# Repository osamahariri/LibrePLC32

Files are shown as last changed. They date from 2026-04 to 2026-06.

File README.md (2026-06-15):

<p align="center">
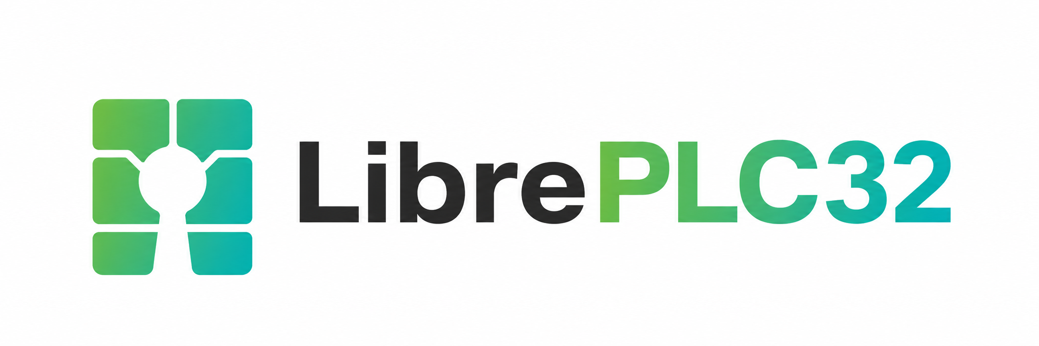
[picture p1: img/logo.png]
LibrePLC32 logo
  
</p>

# LibrePLC32

**LibrePLC32** is an open-source, KiCad-based Programmable Logic Controller (PLC) hardware project.

The goal of the project is to create a compact, hackable, and well-documented PLC platform for industrial automation experiments, prototyping, education, and open hardware development.

> ⚠️ **Work in progress:** LibrePLC32 is currently under development.

<p align="center">
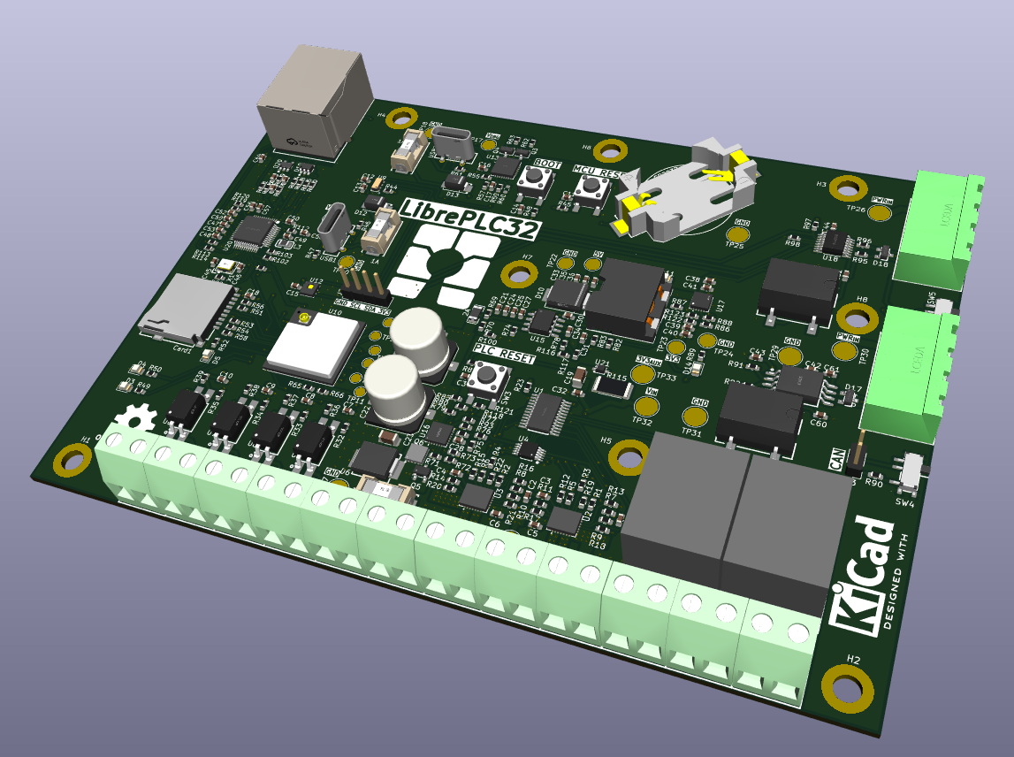
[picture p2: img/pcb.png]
  
</p>

## Project goals

LibrePLC32 aims to provide:

- An open hardware PLC design
- KiCad source files for schematic and PCB development
- Field-oriented interfaces such as digital I/O, isolated CAN, isolated RS-485, and Ethernet
- A design that can be studied, modified, repaired, and improved by the community
- Documentation for design decisions and component calculations

## Repository structure

```text
.
├── img/              # Project logo and graphics
├── plc/
│   ├── docs/         # Design notes and calculations
│   └── kicad/        # KiCad project, schematics, PCB, and libraries
├── LICENSE
└── README.md
```

## Features

LibrePLC32 is designed to provide a practical set of PLC-oriented hardware features:

- **8–36 V DC input voltage range**
- **4 isolated digital inputs** for field signals
- **4 transistor digital outputs** for driving external loads
- **2 relay output terminals** for switching isolated loads
- **Isolated RS-485 interface** for industrial serial communication
- **Isolated CAN bus interface** for device-to-device communication
- **Ethernet interface** for network connectivity

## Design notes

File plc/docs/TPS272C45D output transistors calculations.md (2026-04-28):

# TPS272C45D Output Transistors

Used for outputting power to channels 1-4.

Variant 'D' has dual fault FLT1/FLT2 to provide detailed fault diagnosis.
[Product Link](https://www.ti.com/product/TPS272C45/part-details/TPS272C45DRHFR)

## Current limit

The current limit for each channel is measured using the following formula:
`I_CL = K_CL / R_ILIM`,

with the constant `K_CL` being 20.5 A.kΩ. `R_ILIM` is limited between 5 kΩ and 28.2 kΩ.
Using 5.1 kΩ resistors this will put the output current at a maximum of 4.02 A.

## Current sense
The `SNS` pin outputs a current that is proportional to the load current through either channel, depending on the state of the `SEL` pin.
When the `SEL` is low, `SNS` outputs load current proportional to channel 1, and if `SEL` is high, channel 2.

`I_SNSI = I_OUT / K_SNS`,

with the constant `K_SNS` being 1200.
There is also a low-pass RC filter to improve the current sense value.
Values for `R_PROT`, `C_SNS` are 10 kΩ and 100 pF, and are the recommended ones by TI for common functionality.

`R_SNS` is 620 Ω.

How the `R_SNS` value was chosen:
- the biggest measurable value is 4 A, which is also the limit
- the external ADC, ADS1115 range is +- 4.096 V, but we can use +-2.048 V range, and get finer measurements
- since `V_SNS = I_OUT × R_SNS / K_SNS`, with `I_OUT` variable from 0 to 4 A, `R_SNS` is close to 620 Ω
- this will clip the voltage just under 4 A, but it's reasonable

## Fault indication

`FLT` is active low.

There are 4 types of faults indicated on the `FLT` pins:
- FET thermal shutdown
- Active current regulation
- Thermal shutdown caused by current limitation
- Open-load (FET OFF state only)

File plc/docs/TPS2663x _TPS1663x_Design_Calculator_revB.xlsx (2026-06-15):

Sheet: Instructions
Instructions for using the TPS2663x/TPS1663x Design Calculator
Design Inputs • Enter the design inputs for operating input voltage, under voltage, overvoltage set points, output capacitance, ambient temperature, load at start-up, maximum continuous load current, and permissible inrush current at start up for charging output capacitance in cells D5 to D14 in Calculation Sheet. • Select the current limit for device (ILimit) at-least 5% more than (Imax + IINRUSH_Permissible) in Cell D15 in Calculation Sheet. UVLO, OVP Calculations • Enter the value of resistor (R3) between UVLO and OVP pins in Cell D18 in Calculation in Calculation Sheet • Design Calculator provides the calculated value of R2, R3 • Select the value of R1, R2 and R3 resistors in cells D22 to D24 close to the calculated values. • Design calculator provides the final under voltage, overvoltage and power fail set points based on selected values of R1 to R3 in cells D22 to D24. • Verify the value of current through resistors R1 to R3. The color of cell D28 changes based on value of current. If Current < 2uA, the cell turns RED and value of R3 needs to be reduced. Current Limit Calculations • Design
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

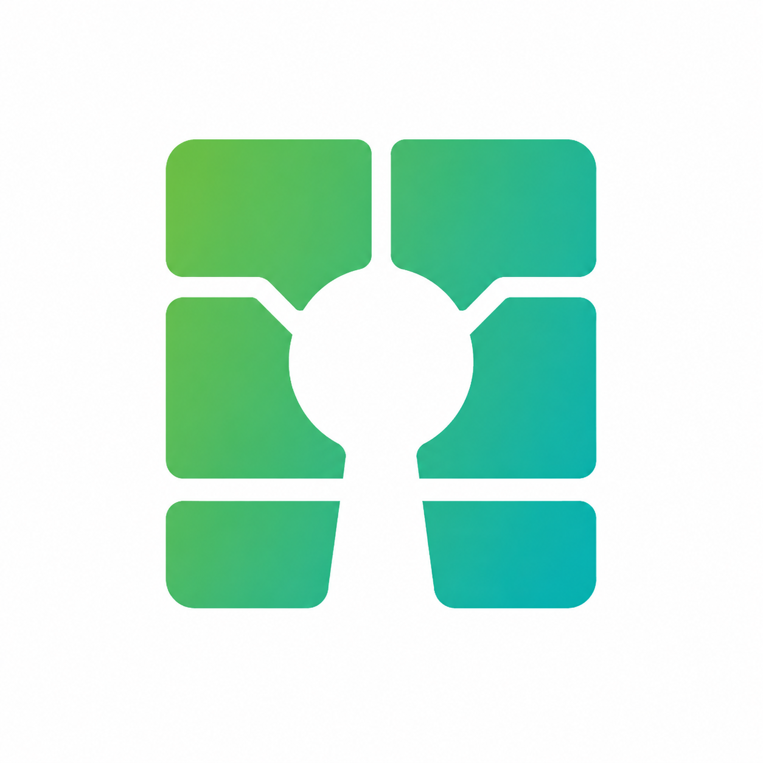
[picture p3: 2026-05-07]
img/symbol.png

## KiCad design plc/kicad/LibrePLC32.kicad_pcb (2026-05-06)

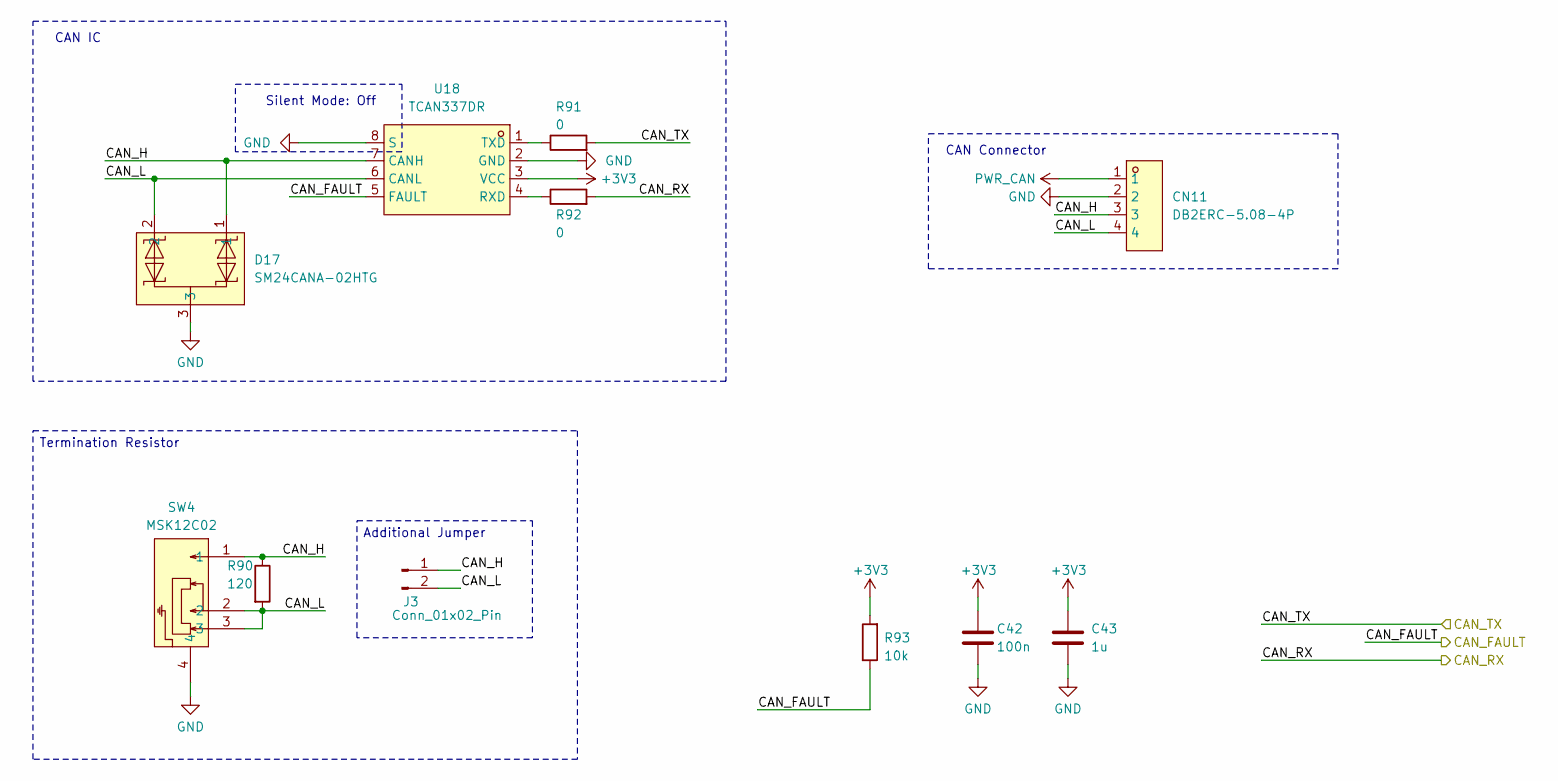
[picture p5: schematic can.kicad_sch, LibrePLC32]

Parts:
C42: 100n; C_0603_1608Metric
C43: 1u; C_0603_1608Metric
CN11: DB2ERC-5.08-4P; CONN-TH_4P-P5.08_DB2ERC-5.08-4P; MPN DB2ERC-5.08-4P-GN; LCSC Part C395753
D17: SM24CANA-02HTG; SOT-23_L2.9-W1.3-P1.90-LS2.4-BR; MPN SM24CANA-02HTG; LCSC Part C151236
J3: Conn_01x02_Pin; PinSocket_1x02_P2.54mm_Vertical
R90: 120; R_0603_1608Metric
R91, R92: 0; R_0603_1608Metric
R93: 10k; R_0603_1608Metric
SW4: MSK12C02; SW-TH_MSK12C02; MPN MSK12C02; LCSC Part C431540
U18: TCAN337DR; SOIC-8_L4.9-W3.9-P1.27-LS6.0-BL; MPN TCAN337DR; LCSC Part C2860648

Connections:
+3V3: C42.1, C43.1, R93.2, U18.3 (VCC); also elsewhere on the board
/CAN/CAN_FAULT: R93.1, U18.5 (FAULT); also elsewhere on the board
/CAN/CAN_H: CN11.3, D17.1, J3.1, R90.1, SW4.1, U18.7 (CANH)
/CAN/CAN_L: CN11.4, D17.2, J3.2, R90.2, SW4.2, SW4.3, U18.6 (CANL)
/CAN/CAN_RX: R92.2; also elsewhere on the board
/CAN/CAN_TX: R91.2; also elsewhere on the board
GND: C42.2, C43.2, CN11.2, D17.3, SW4.4, U18.2 (GND), U18.8 (S); also elsewhere on the board
unnamed: R92.1, U18.4 (RXD)
unnamed: R91.1, U18.1 (TXD)
PWR_CAN: CN11.1; also elsewhere on the board

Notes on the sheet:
CAN Connector
Additional Jumper
Termination Resistor
CAN IC
Silent Mode: Off

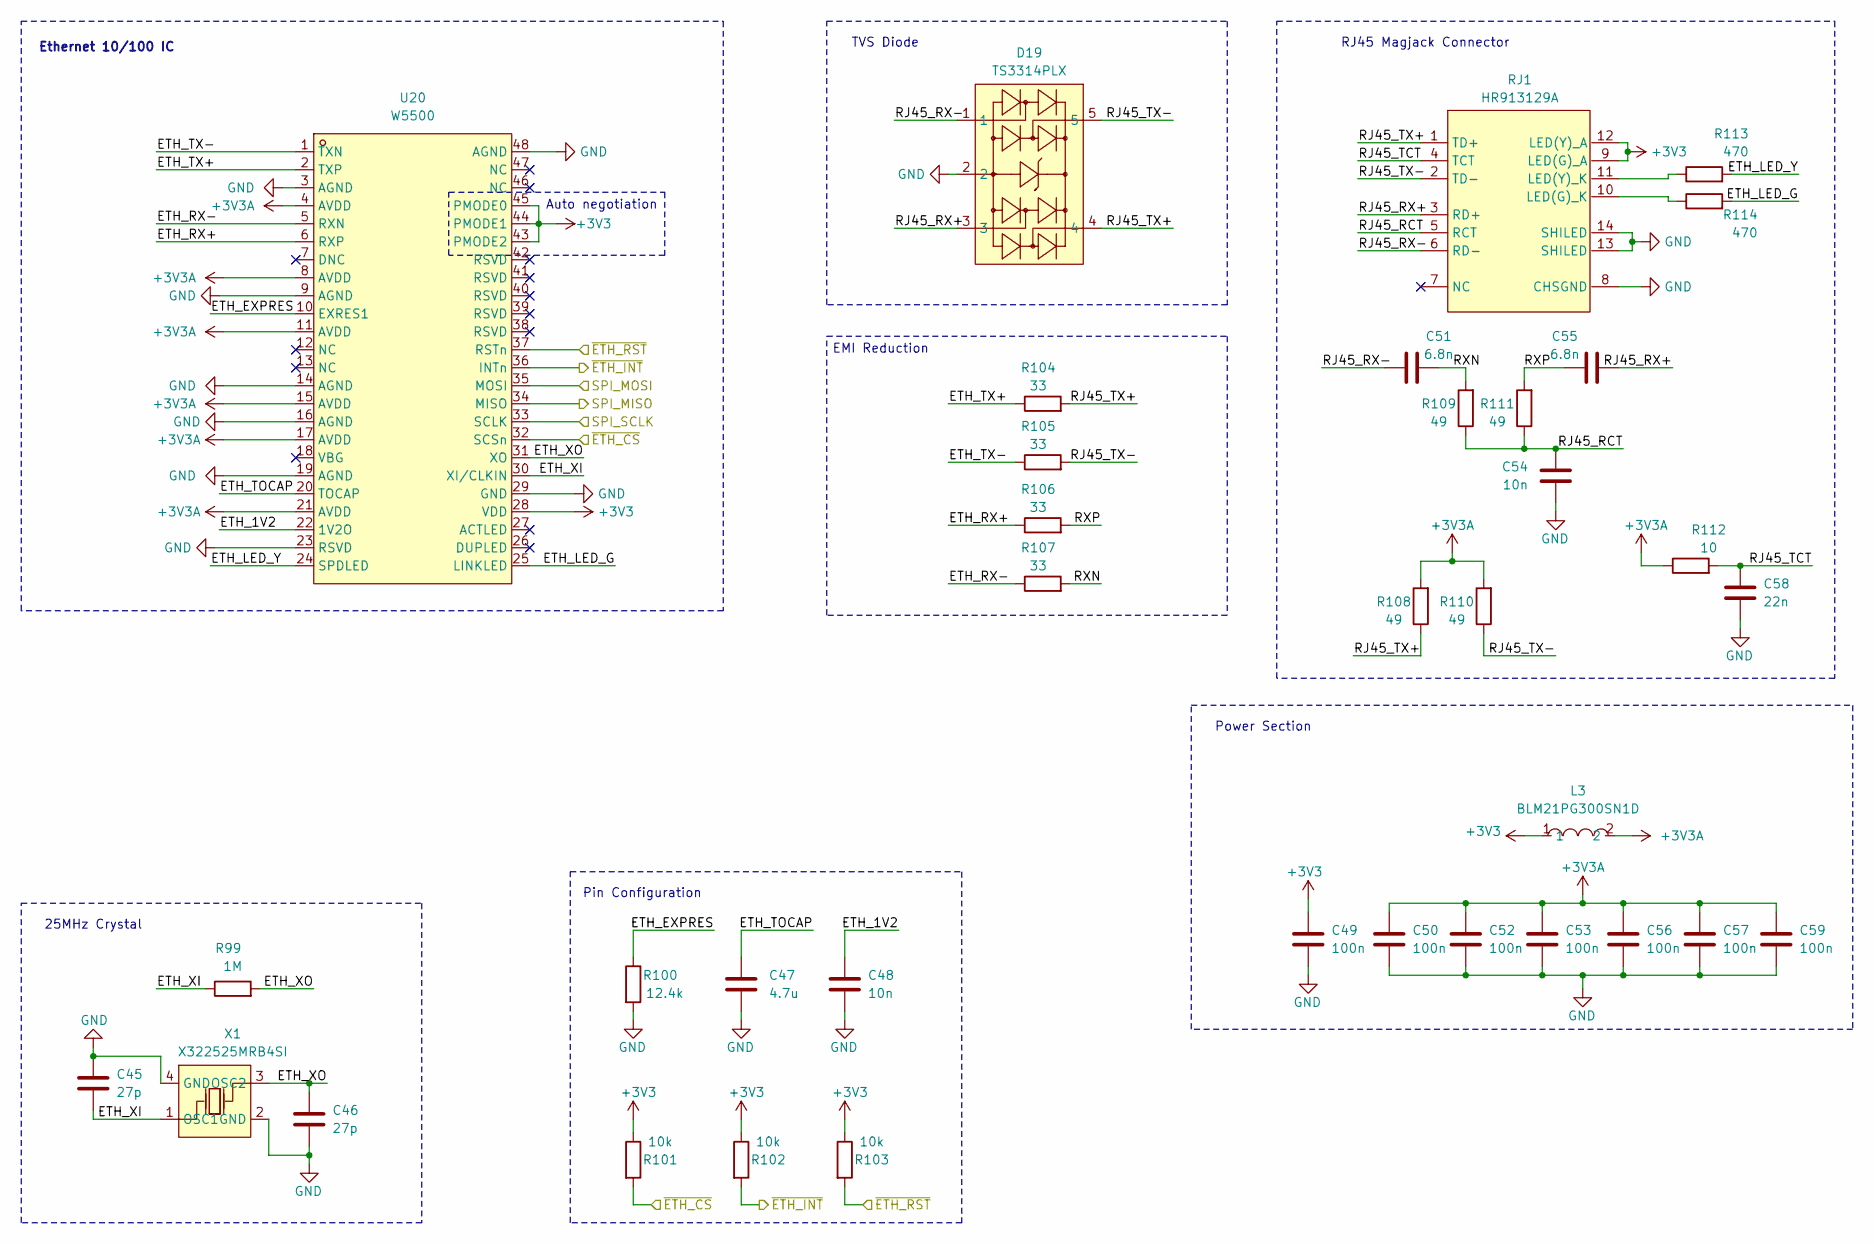
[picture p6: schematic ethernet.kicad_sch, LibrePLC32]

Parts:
C45, C46: 27p; C_0603_1608Metric
C47: 4.7u; C_0603_1608Metric
C48, C54: 10n; C_0603_1608Metric
C49, C50, C52, C53, C56, C57, C59: 100n; C_0603_1608Metric
C51, C55: 6.8n; C_0603_1608Metric
C58: 22n; C_0603_1608Metric
D19: TS3314PLX; SOT-23-5_L2.9-W1.6-P0.95-LS2.8-BR; MPN TS3314PLX; LCSC Part C5156700
L3: BLM21PG300SN1D; L0805; MPN BLM21PG300SN1D; LCSC Part C16903
R99: 1M; R_0603_1608Metric
R100: 12.4k; R_0603_1608Metric
R101, R102, R103: 10k; R_0603_1608Metric
R104, R105, R106, R107: 33; R_0603_1608Metric
R108, R109, R110, R111: 49; R_0603_1608Metric
R112: 10; R_0603_1608Metric
R113, R114: 470; R_0603_1608Metric
RJ1: HR913129A; RJ45-TH_HR913129A; MPN HR913129A; LCSC Part C70302
U20: W5500; LQFP-48_L7.0-W7.0-P0.50-LS9.0-BL; MPN W5500; LCSC Part C32843
X1: X322525MRB4SI; OSC-SMD_4P-L3.2-W2.5-BL_SIT8008BI; MPN X322525MRB4SI; LCSC Part C70593

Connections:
+3V3: C49.1, L3.1, R101.1, R102.1, R103.1, RJ1.9 (LED(G)_A), RJ1.12 (LED(Y)_A), U20.28 (VDD), U20.43 (PMODE2), U20.44 (PMODE1), U20.45 (PMODE0); also elsewhere on the board
+3V3A: C50.1, C52.1, C53.1, C56.1, C57.1, C59.1, L3.2, R108.2, R110.2, R112.1, U20.4 (AVDD), U20.8 (AVDD), U20.11 (AVDD), U20.15 (AVDD), U20.17 (AVDD), U20.21 (AVDD)
/Ethernet/ETH_1V2: C48.1, U20.22 (1V2O)
/Ethernet/ETH_EXPRES: R100.1, U20.10 (EXRES1)
/Ethernet/ETH_LED_G: R114.2, U20.25 (LINKLED)
/Ethernet/ETH_LED_Y: R113.2, U20.24 (SPDLED)
/Ethernet/ETH_RX+: R106.1, U20.6 (RXP)
/Ethernet/ETH_RX-: R107.1, U20.5 (RXN)
/Ethernet/ETH_TOCAP: C47.1, U20.20 (TOCAP)
/Ethernet/ETH_TX+: R104.1, U20.2 (TXP)
/Ethernet/ETH_TX-: R105.1, U20.1 (TXN)
/Ethernet/ETH_XI: C45.2, R99.1, U20.30 (XI/CLKIN), X1.1 (OSC1)
/Ethernet/ETH_XO: C46.1, R99.2, U20.31 (XO), X1.3 (OSC2)
/Ethernet/RJ45_RCT: C54.1, R109.1, R111.1, RJ1.5 (RCT)
/Ethernet/RJ45_RX+: C55.2, D19.3, RJ1.3 (RD+)
/Ethernet/RJ45_RX-: C51.2, D19.1, RJ1.6 (RD-)
/Ethernet/RJ45_TCT: C58.1, R112.2, RJ1.4 (TCT)
/Ethernet/RJ45_TX+: D19.4, R104.2, R108.1, RJ1.1 (TD+)
/Ethernet/RJ45_TX-: D19.5, R105.2, R110.1, RJ1.2 (TD-)
/Ethernet/RXN: C51.1, R107.2, R109.2
/Ethernet/RXP: C55.1, R106.2, R111.2
/Ethernet/SPI_MISO: U20.34 (MISO); also elsewhere on the board
/Ethernet/SPI_MOSI: U20.35 (MOSI); also elsewhere on the board
/Ethernet/SPI_SCLK: U20.33 (SCLK); also elsewhere on the board
/Ethernet/~ETH_CS: R101.2, U20.32 (SCSn); also elsewhere on the board
/Ethernet/~ETH_INT: R102.2, U20.36 (INTn); also elsewhere on the board
/Ethernet/~ETH_RST: R103.2, U20.37 (RSTn); also elsewhere on the board
GND: C45.1, C46.2, C47.2, C48.2, C49.2, C50.2, C52.2, C53.2, C54.2, C56.2, C57.2, C58.2, C59.2, D19.2, R100.2, RJ1.8 (CHSGND), RJ1.13 (SHILED), RJ1.14 (SHILED), U20.3 (AGND), U20.9 (AGND), U20.14 (AGND), U20.16 (AGND), U20.19 (AGND), U20.23 (RSVD), U20.29 (GND), U20.48 (AGND), X1.2 (GND), X1.4 (GND); also elsewhere on the board
unnamed: R114.1, RJ1.10 (LED(G)_K)
unnamed: R113.1, RJ1.11 (LED(Y)_K)

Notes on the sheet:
Auto negotiation
Ethernet 10/100 IC
EMI Reduction
TVS Diode
Power Section
Pin Configuration
25MHz Crystal
RJ45 Magjack Connector

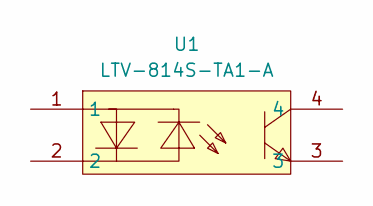
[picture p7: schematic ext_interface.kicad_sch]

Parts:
U1: LTV-814S-TA1-A; OPTO-SMD-4_L4.6-W6.5-P2.54-LS10.3-BL; MPN LTV-814S-TA1-A; LCSC Part C108051

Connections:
/Terminal Blocks Interface/T1_EN1: U1.4 (P00); also elsewhere on the board
/Terminal Blocks Interface/~GPIO_MUX_INT: U1.1 (~INT); also elsewhere on the board
GND: U1.2 (A1), U1.3 (A2); also elsewhere on the board

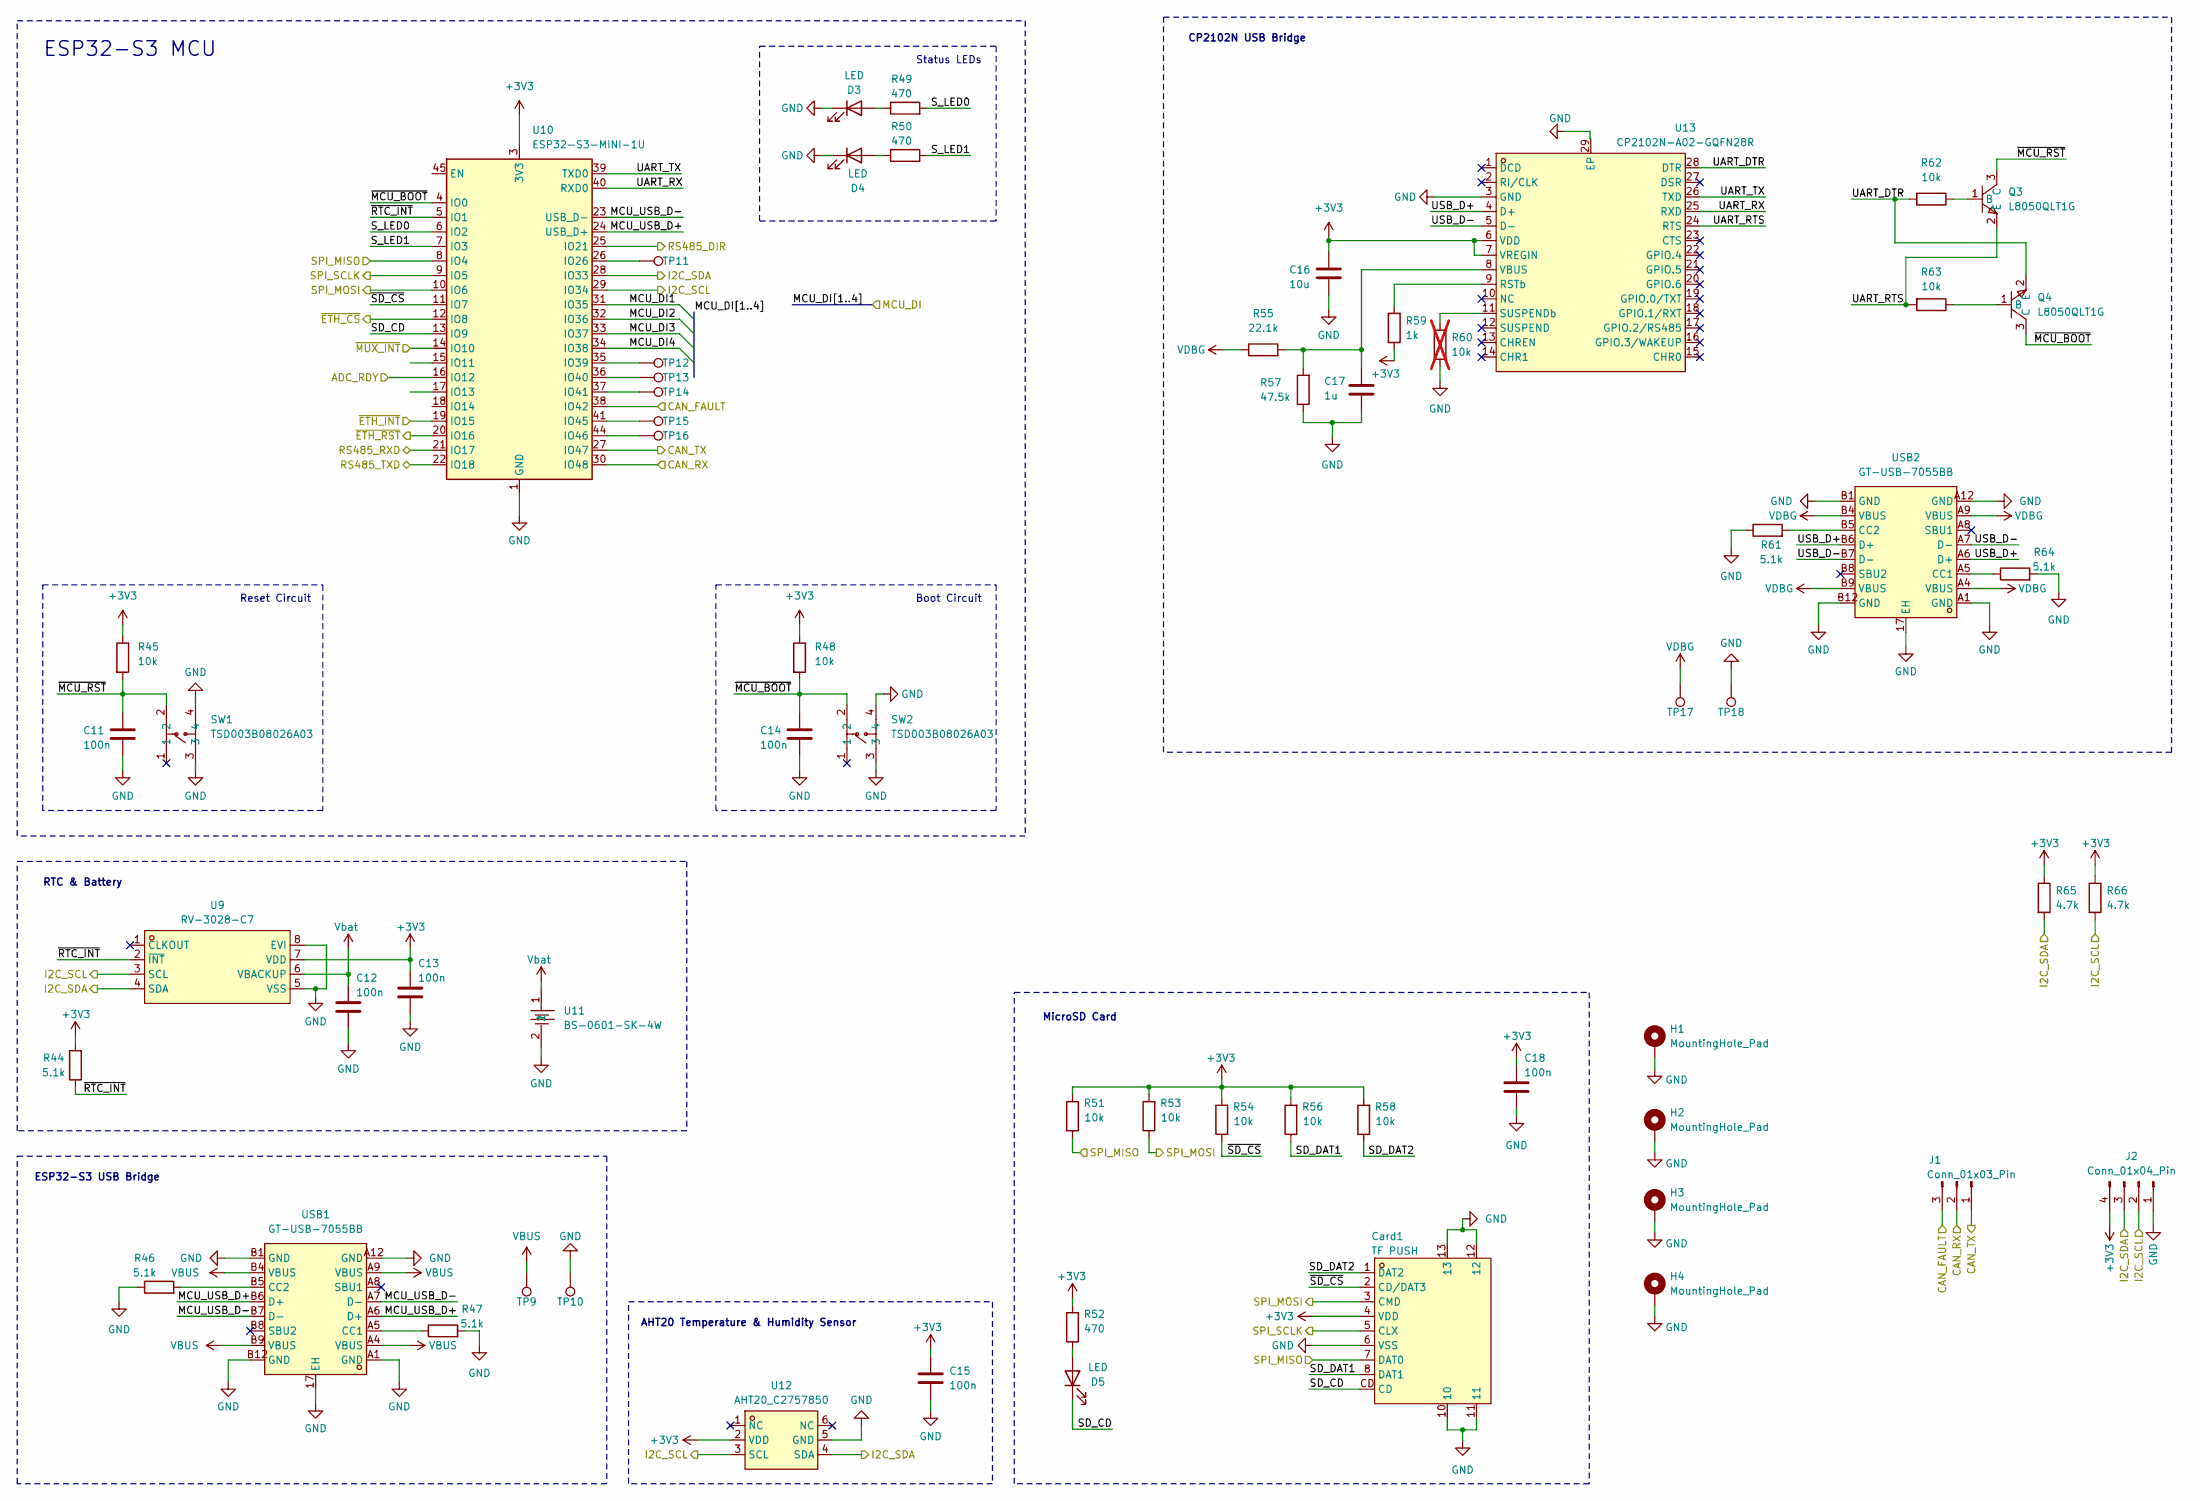
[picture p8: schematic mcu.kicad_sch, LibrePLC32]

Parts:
C11, C12, C13, C14, C15, C18: 100n; C_0603_1608Metric
C16: 10u; C_0603_1608Metric
C17: 1u; C_0603_1608Metric
Card1: TF PUSH; TF-SMD_TF-PUSH; MPN TF PUSH; LCSC Part C393941
D3, D4, D5: LED; LED_0805_2012Metric
H1, H2, H3, H4: MountingHole_Pad; MountingHole_4.3mm_M4_DIN965_Pad_TopBottom
J1: Conn_01x03_Pin
J2: Conn_01x04_Pin; PinSocket_1x04_P2.54mm_Vertical
Q3, Q4: L8050QLT1G; SOT-23-3_L2.9-W1.3-P1.90-LS2.4-BR; MPN L8050QLT1G; LCSC Part C49581
R44, R46, R47, R61, R64: 5.1k; R_0603_1608Metric
R45, R48, R51, R53, R54, R56, R58, R62, R63: 10k; R_0603_1608Metric
R49, R50, R52: 470; R_0603_1608Metric
R55: 22.1k; R_0603_1608Metric
R57: 47.5k; R_0603_1608Metric
R59: 1k; R_0603_1608Metric
R60: 10k; R_0603_1608Metric; not fitted
R65, R66: 4.7k; R_0603_1608Metric
SW1, SW2: TSD003B08026A03; SW-SMD_4P-L6.0-W6.0-P4.50-LS8.6; MPN TSD003B08026A03; LCSC Part C2888805
TP9, TP10, TP17, TP18: TestPoint; TestPoint_Pad_D3.0mm
TP11, TP12, TP13, TP14, TP15, TP16: TestPoint; TestPoint_Pad_D2.0mm
U9: RV-3028-C7; OSC-SMD_8P-L3.2-W1.5-P0.90-BL; MPN RV-3028-C7-32.768kHz-1ppm-TA-QC; LCSC Part C3019759
U10: ESP32-S3-MINI-1U; BULETM-SMD_ESPRESSIF_ESP32-S3-MINI-1U-N8
U11: BS-0601-SK-4W; BAT-SMD_BS-06-B4AA012; MPN BS-0601-SK-4W; LCSC Part C19089122
U12: AHT20_C2757850; SENSOR-SMD_L3.0-W3.0-P1.00-BR; MPN AHT20; LCSC Part C2757850
U13: CP2102N-A02-GQFN28R; QFN-28_L5.0-W5.0-P0.50-TL-EP3.3; MPN CP2102N-A02-GQFN28R; LCSC Part C964632
USB1, USB2: GT-USB-7055BB; USB-C-TH_GT-USB-7055BB; MPN GT-USB-7055BB; LCSC Part C7450621

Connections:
+3V3: C13.2, C15.1, C16.2, C18.2, Card1.4 (VDD), J2.4, R44.2, R45.1, R48.1, R51.2, R52.2, R53.2, R54.2, R56.2, R58.2, R59.1, R65.1, R66.1, U9.7 (VDD), U10.3 (3V3), U12.2 (VDD), U13.6 (VDD), U13.7 (VREGIN); also elsewhere on the board
/CAN/CAN_FAULT: J1.3, U10.38 (IO42); also elsewhere on the board
/CAN/CAN_RX: J1.2, U10.30 (IO48); also elsewhere on the board
/CAN/CAN_TX: J1.1, U10.27 (IO47); also elsewhere on the board
/Ethernet/SPI_MISO: Card1.7 (DAT0), R51.1, U10.8 (IO4); also elsewhere on the board
/Ethernet/SPI_MOSI: Card1.3 (CMD), R53.1, U10.10 (IO6); also elsewhere on the board
/Ethernet/SPI_SCLK: Card1.5 (CLX), U10.9 (IO5); also elsewhere on the board
/Ethernet/~ETH_CS: U10.12 (IO8); also elsewhere on the board
/Ethernet/~ETH_INT: U10.19 (IO15); also elsewhere on the board
/Ethernet/~ETH_RST: U10.20 (IO16); also elsewhere on the board
/MCU/ADC_RDY: U10.16 (IO12); also elsewhere on the board
/MCU/I2C_SCL: J2.2, R66.2, U9.3 (SCL), U10.29 (IO34), U12.3 (SCL); also elsewhere on the board
/MCU/I2C_SDA: J2.3, R65.2, U9.4 (SDA), U10.28 (IO33), U12.4 (SDA); also elsewhere on the board
/MCU/MCU_DI1: U10.31 (IO35); also elsewhere on the board
/MCU/MCU_DI2: U10.32 (IO36); also elsewhere on the board
/MCU/MCU_DI3: U10.33 (IO37); also elsewhere on the board
/MCU/MCU_DI4: U10.34 (IO38); also elsewhere on the board
/MCU/MCU_USB_D+: U10.24 (USB_D+), USB1.A6 (D+), USB1.B6 (D+)
/MCU/MCU_USB_D-: U10.23 (USB_D-), USB1.A7 (D-), USB1.B7 (D-)
/MCU/SD_CD: Card1.CD, D5.1 (K), U10.13 (IO9)
/MCU/SD_DAT1: Card1.8 (DAT1), R56.1
/MCU/SD_DAT2: Card1.1 (DAT2), R58.1
/MCU/S_LED0: R49.2, U10.6 (IO2)
/MCU/S_LED1: R50.2, U10.7 (IO3)
/MCU/UART_DTR: Q4.2 (E), R62.2, U13.28 (DTR)
/MCU/UART_RTS: Q3.2 (E), R63.2, U13.24 (RTS)
/MCU/UART_RX: U10.40 (RXD0), U13.25 (RXD)
/MCU/UART_TX: U10.39 (TXD0), U13.26 (TXD)
/MCU/USB_D+: U13.4 (D+), USB2.A6 (D+), USB2.B6 (D+)
/MCU/USB_D-: U13.5 (D-), USB2.A7 (D-), USB2.B7 (D-)
/MCU/~MCU_BOOT: C14.2, Q4.3 (C), R48.2, SW2.2, U10.4 (IO0)
/MCU/~MCU_RST: C11.2, Q3.3 (C), R45.2, SW1.2
/MCU/~RTC_INT: R44.1, U9.2 (~INT), U10.5 (IO1)
/MCU/~SD_CS: Card1.2 (CD/DAT3), R54.1, U10.11 (IO7)
/RS-485/RS485_DIR: U10.25 (IO21); also elsewhere on the board
/RS-485/RS485_RXD: U10.21 (IO17); also elsewhere on the board
/RS-485/RS485_TXD: U10.22 (IO18); also elsewhere on the board
/Terminal Blocks Interface/~GPIO_MUX_INT: U10.14 (IO10); also elsewhere on the board
GND: C11.1, C12.1, C13.1, C14.1, C15.2, C16.1, C17.2, C18.1, Card1.6 (VSS), Card1.10, Card1.11, Card1.12, Card1.13, D3.1 (K), D4.1 (K), H1.1 (1_1), H2.1 (1_1), H3.1 (1_1), H4.1 (1_1), J2.1, R46.1, R47.2, R57.1, R60.1, R61.1, R64.2, SW1.3, SW1.4, SW2.3, SW2.4, TP10.1 (1_1), TP18.1 (1_1), U9.5 (VSS), U9.8 (EVI), U10.1 (GND), U10.2 (GND), U10.42 (GND), U10.43 (GND), U10.46 (GND), U10.47 (GND), U10.48 (GND), U10.49 (GND), U10.50 (GND), U10.51 (GND), U10.52 (GND), U10.53 (GND), U10.54 (GND), U10.55 (GND), U10.56 (GND), U10.57 (GND), U10.58 (GND), U10.59 (GND), U10.60 (GND), U10.61 (GND), U10.62 (GND), U10.63 (GND), U10.64 (GND), U10.65 (GND), U11.2, U12.5 (GND), U13.3 (GND), U13.29 (EP), USB1.17 (EH), USB1.A1 (GND), USB1.A12 (GND), USB1.B1 (GND), USB1.B12 (GND), USB2.17 (EH), USB2.A1 (GND), USB2.A12 (GND), USB2.B1 (GND), USB2.B12 (GND); also elsewhere on the board
unnamed: D3.2 (A), R49.1
unnamed: D4.2 (A), R50.1
unnamed: D5.2 (A), R52.1
unnamed: Q3.1 (B), R62.1
unnamed: Q4.1 (B), R63.1
unnamed: TP11.1 (1_1), U10.26 (IO26)
unnamed: TP12.1 (1_1), U10.35 (IO39)
unnamed: TP13.1 (1_1), U10.36 (IO40)
unnamed: TP14.1 (1_1), U10.37 (IO41)
unnamed: TP15.1 (1_1), U10.41 (IO45)
unnamed: TP16.1 (1_1), U10.44 (IO46)
unnamed: R59.2, U13.9 (RSTb)
unnamed: R60.2, U13.11 (SUSPENDb)
unnamed: C17.1, R55.2, R57.2, U13.8 (VBUS)
unnamed: R47.1, USB1.A5 (CC1)
unnamed: R46.2, USB1.B5 (CC2)
unnamed: R64.1, USB2.A5 (CC1)
unnamed: R61.2, USB2.B5 (CC2)
VBUS: TP9.1 (1_1), USB1.A4 (VBUS), USB1.A9 (VBUS), USB1.B4 (VBUS), USB1.B9 (VBUS); also elsewhere on the board
VDBG: R55.1, TP17.1 (1_1), USB2.A4 (VBUS), USB2.A9 (VBUS), USB2.B4 (VBUS), USB2.B9 (VBUS); also elsewhere on the board
Vbat: C12.2, U9.6 (VBACKUP), U11.1

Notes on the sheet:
MicroSD Card
Status LEDs
AHT20 Temperature & Humidity Sensor
Reset Circuit
RTC & Battery
CP2102N USB Bridge
Boot Circuit
ESP32-S3 USB Bridge
ESP32-S3 MCU

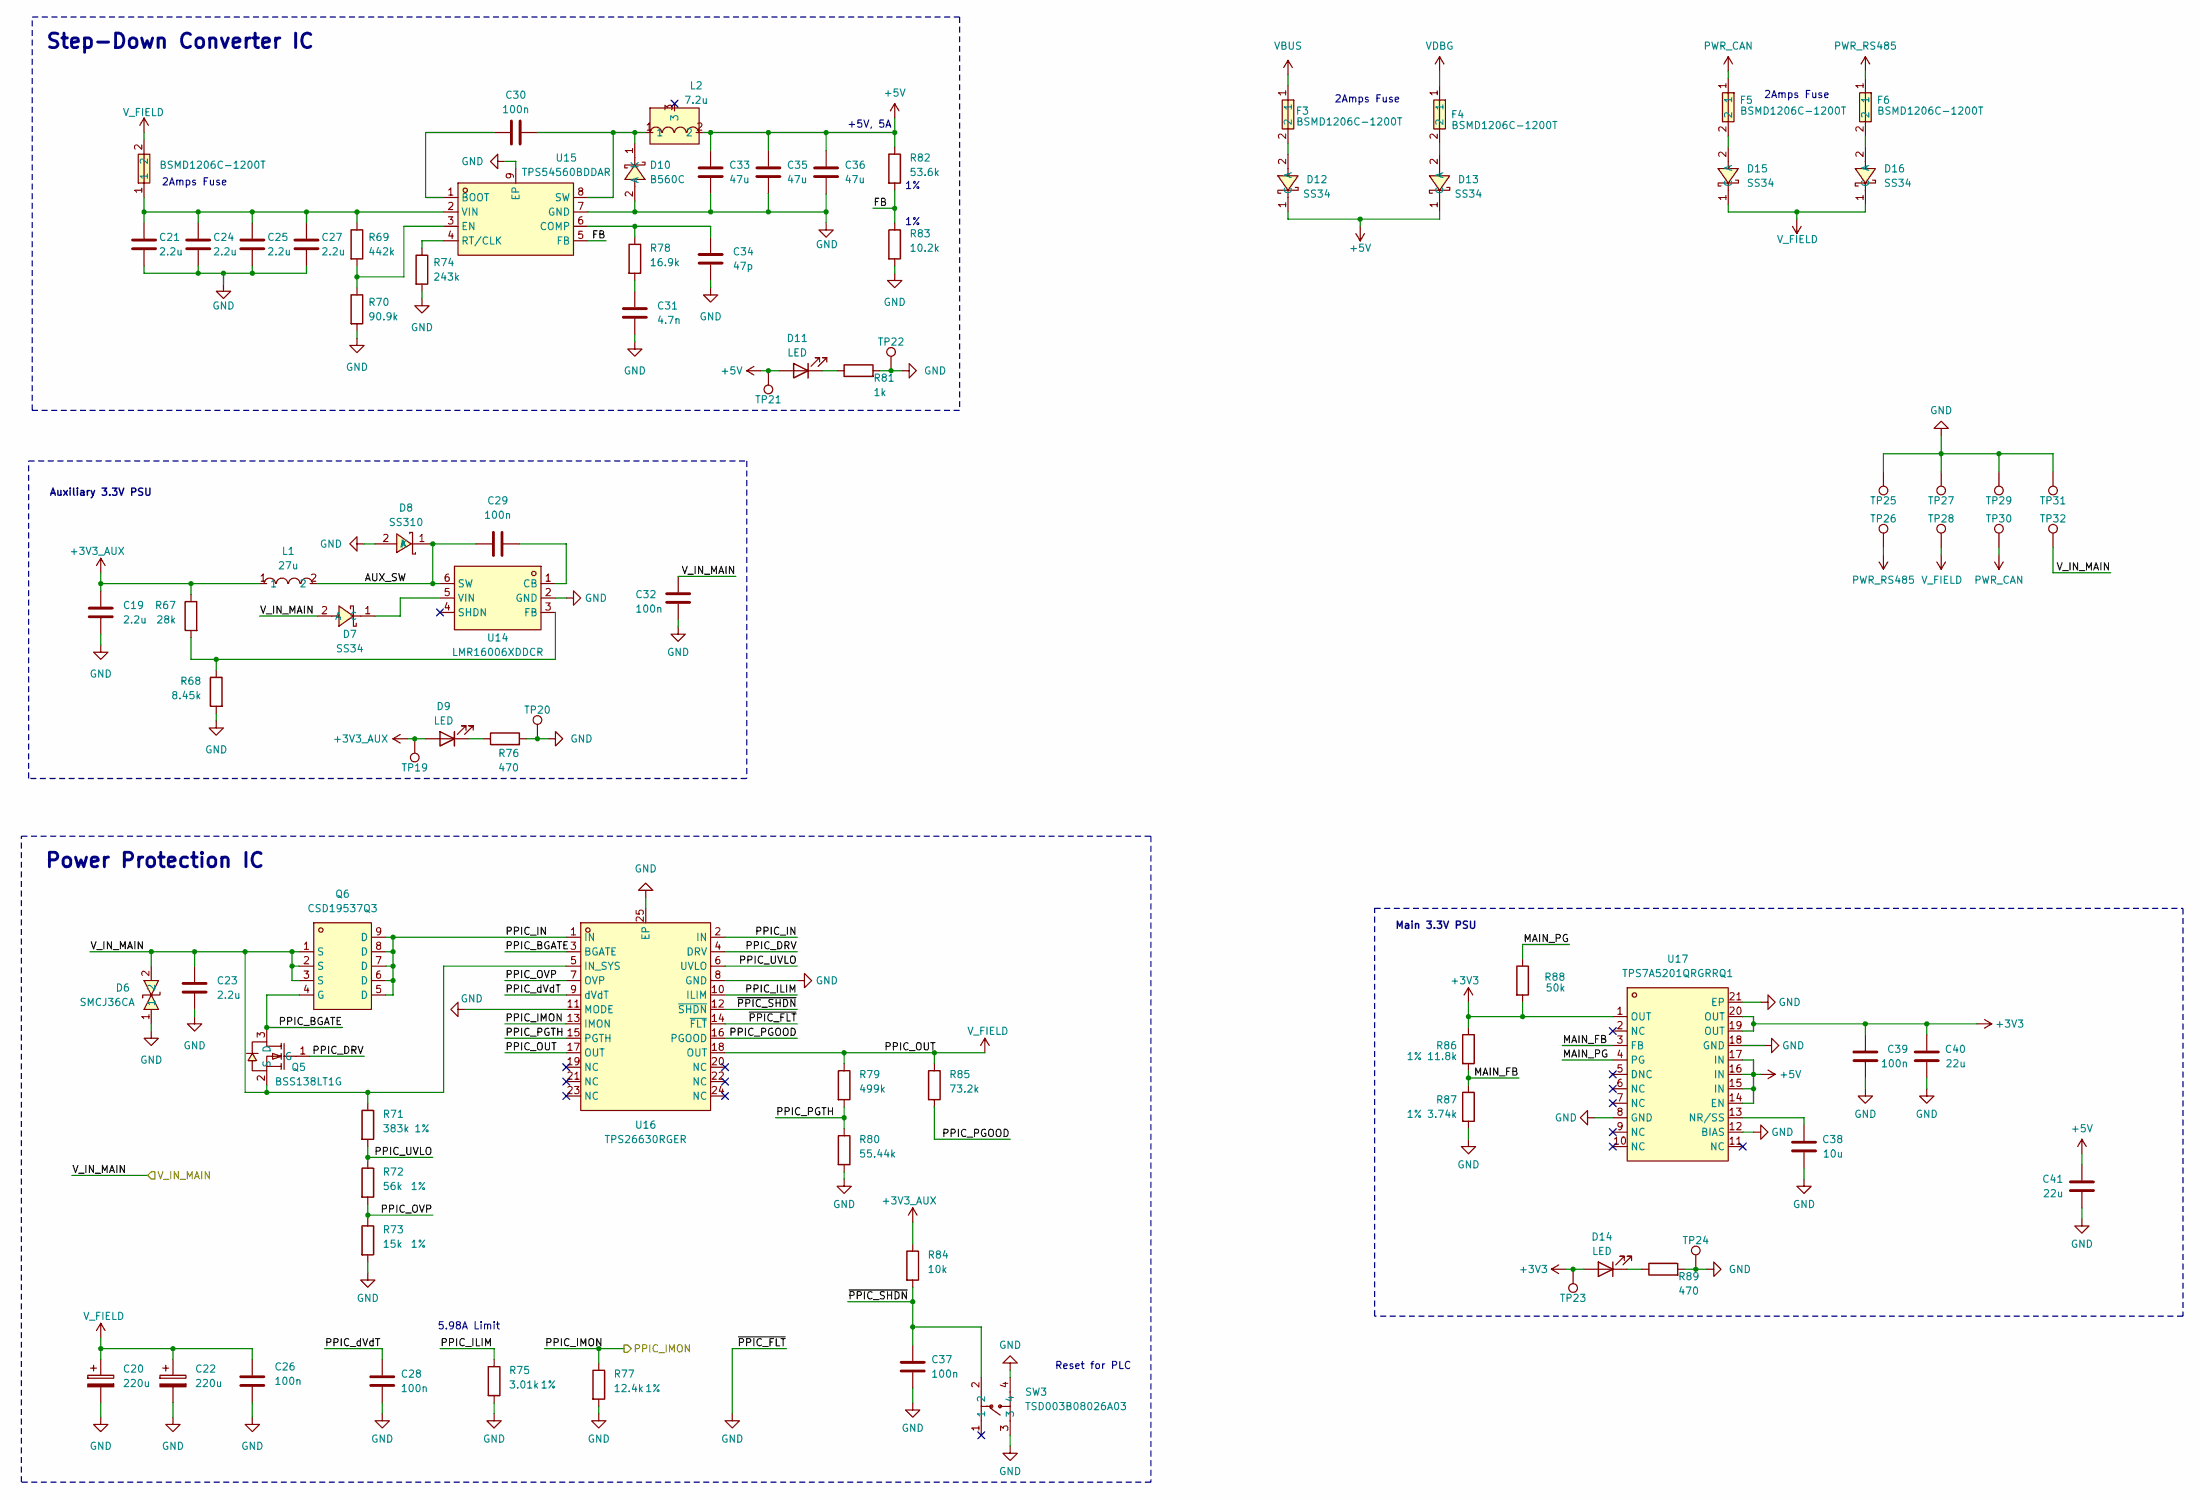
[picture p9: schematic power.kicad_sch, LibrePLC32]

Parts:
C19, C23: 2.2u; C_1206_3216Metric
C20, C22: 220u; C_Elec_10x10.2; LCSC Part C125977
C21, C24, C25, C27: 2.2u; C_0603_1608Metric
C26, C28, C29, C30, C32, C37, C39: 100n; C_0603_1608Metric
C31: 4.7n; C_0603_1608Metric
C33, C35, C36: 47u; C_0603_1608Metric
C34: 47p; C_0603_1608Metric
C38: 10u; C_0603_1608Metric
C40: 22u; C_0603_1608Metric; LCSC Part C86295
C41: 22u; C_0603_1608Metric
D6: SMCJ36CA; SMC_L6.9-W5.9-LS7.9-BI; MPN SMCJ36CA; LCSC Part C151283
D7, D12, D13, D15, D16: SS34; SMA_L4.3-W2.7-LS5.1-RD; MPN SS34; LCSC Part C908680
D8: SS310; SMB_L4.6-W3.6-LS5.3-RD; MPN SS310B; LCSC Part C14281
D9, D11, D14: LED; LED_0805_2012Metric
D10: B560C; SMC_L6.9-W5.9-LS7.9-RD; MPN B560C; LCSC Part C6807784
F2, F3, F4, F5, F6: BSMD1206C-1200T; F1206; MPN BSMD1206C-1200T; LCSC Part C41367223
L1: 27u; IND-SMD_L3.5-W3.0_SLF0302; MPN ASPI-0315S-270M-T; LCSC Part C187267
L2: 7.2u; IND-SMD_3P-L13.5-W13.0-P6.9; MPN XRCEP125-7R2M; LCSC Part C41368782
Q5: BSS138LT1G; SOT-23-3_L2.9-W1.6-P1.90-LS2.8-BR; MPN BSS138LT1G; LCSC Part C82045
Q6: CSD19537Q3; DFN-8_L3.3-W3.3-P0.65-BL-3; MPN CSD19537Q3; LCSC Part C478469
R67: 28k; R_0603_1608Metric
R68: 8.45k; R_0603_1608Metric
R69: 442k; R_0603_1608Metric
R70: 90.9k; R_0603_1608Metric
R71: 383k; R_0603_1608Metric; Tolerance 1%
R72: 56k; R_0603_1608Metric; Tolerance 1%
R73: 15k; R_0603_1608Metric; Tolerance 1%
R74: 243k; R_0603_1608Metric
R75: 3.01k; R_0603_1608Metric; Tolerance 1%
R76, R89: 470; R_0603_1608Metric
R77: 12.4k; R_0603_1608Metric; Tolerance 1%
R78: 16.9k; R_0603_1608Metric
R79: 499k; R_0603_1608Metric
R80: 55.44k; R_0603_1608Metric
R81: 1k; R_0603_1608Metric
R82: 53.6k; R_0603_1608Metric
R83: 10.2k; R_0603_1608Metric
R84: 10k; R_0603_1608Metric
R85: 73.2k; R_0603_1608Metric
R86: 11.8k; R_0603_1608Metric; Tolerance 1%
R87: 3.74k; R_0603_1608Metric; Tolerance 1%
R88: 50k; R_0603_1608Metric
SW3: TSD003B08026A03; SW-SMD_4P-L6.0-W6.0-P4.50-LS8.6; MPN TSD003B08026A03; LCSC Part C2888805
TP19, TP20, TP21, TP22, TP23, TP24: TestPoint; TestPoint_Pad_D3.0mm
TP25, TP26, TP27, TP28, TP29, TP30, TP31, TP32: TestPoint; TestPoint_Pad_D4.0mm
U14: LMR16006XDDCR; SOT-23-6_L2.9-W1.6-P0.95-LS2.8-BR; MPN LMR16006XDDCR; LCSC Part C87080
U15: TPS54560BDDAR; POWERPAD-SO-8_L4.9-W3.9-P1.27-LS6.0-BL-EP; MPN TPS54560BDDAR; LCSC Part C1850354
U16: TPS26630RGER; TQFN-24_L4.0-W4.0-P0.50-TL-EP; MPN TPS26630RGER(TOKMAS); LCSC Part C52940996
U17: TPS7A5201QRGRRQ1; VQFN-20_L3.5-W3.5-P0.50-TL-EP; MPN TPS7A5201QRGRRQ1; LCSC Part C523802

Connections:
+3V3: C39.2, C40.2, D14.2 (A), R86.1, R88.2, TP23.1 (1_1), U17.1 (OUT), U17.19 (OUT), U17.20 (OUT); also elsewhere on the board
+3V3_AUX: C19.1, D9.2 (A), L1.1, R67.1, R84.1, TP19.1 (1_1)
+5V: C33.2, C35.2, C36.2, C41.2, D11.2 (A), D12.1 (C), D13.1 (C), L2.2, R82.1, TP21.1 (1_1), U17.14 (EN), U17.15 (IN), U17.16 (IN), U17.17 (IN); also elsewhere on the board
/Power/AUX_SW: C29.2, D8.1 (K), L1.2, U14.6 (SW)
/Power/FB: R82.2, R83.1, U15.5 (FB)
/Power/MAIN_FB: R86.2, R87.1, U17.3 (FB)
/Power/MAIN_PG: R88.1, U17.4 (PG)
/Power/PPIC_BGATE: Q5.3 (D), Q6.4 (G), U16.3 (BGATE)
/Power/PPIC_DRV: Q5.1 (G), U16.4 (DRV)
/Power/PPIC_ILIM: R75.1, U16.10 (ILIM)
/Power/PPIC_IMON: R77.1, U16.13 (IMON); also elsewhere on the board
/Power/PPIC_IN: Q6.5 (D), Q6.6 (D), Q6.7 (D), Q6.8 (D), Q6.9 (D), U16.1 (IN), U16.2 (IN)
/Power/PPIC_OVP: R72.2, R73.1, U16.7 (OVP)
/Power/PPIC_PGOOD: R85.2, U16.16 (PGOOD)
/Power/PPIC_PGTH: R79.2, R80.1, U16.15 (PGTH)
/Power/PPIC_UVLO: R71.2, R72.1, U16.6 (UVLO)
/Power/PPIC_dVdT: C28.2, U16.9 (dVdT)
/Power/V_IN_MAIN: C23.2, C32.2, D6.2, D7.2 (A), Q5.2 (S), Q6.1 (S), Q6.2 (S), Q6.3 (S), R71.1, TP32.1 (1_1), U16.5 (IN_SYS); also elsewhere on the board
/Power/~PPIC_SHDN: C37.2, R84.2, SW3.2, U16.12 (~SHDN)
GND: C19.2, C20.2, C21.2, C22.2, C23.1, C24.2, C25.2, C26.1, C27.2, C28.1, C31.1, C32.1, C33.1, C34.1, C35.1, C36.1, C37.1, C38.1, C39.1, C40.1, C41.1, D6.1, D8.2 (A), D10.2 (A), R68.2, R70.2, R73.2, R74.2, R75.2, R76.2, R77.2, R80.2, R81.2, R83.2, R87.2, R89.2, SW3.3, SW3.4, TP20.1 (1_1), TP22.1 (1_1), TP24.1 (1_1), TP25.1 (1_1), TP27.1 (1_1), TP29.1 (1_1), TP31.1 (1_1), U14.2 (GND), U15.7 (GND), U15.9 (EP), U16.8 (GND), U16.11 (MODE), U16.14 (~FLT), U16.25 (EP), U17.8 (GND), U17.12 (BIAS), U17.18 (GND), U17.21 (EP); also elsewhere on the board
unnamed: C31.2, R78.2
unnamed: D7.1 (C), U14.5 (VIN)
unnamed: D9.1 (K), R76.1
unnamed: C30.2, D10.1 (K), L2.1, U15.8 (SW)
unnamed: D11.1 (K), R81.1
unnamed: D12.2 (A), F3.2
unnamed: D13.2 (A), F4.2
unnamed: D14.1 (K), R89.1
unnamed: D15.2 (A), F5.2
unnamed: D16.2 (A), F6.2
unnamed: C29.1, U14.1 (CB)
unnamed: R67.2, R68.1, U14.3 (FB)
unnamed: C30.1, U15.1 (BOOT)
unnamed: C34.2, R78.1, U15.6 (COMP)
unnamed: R69.2, R70.1, U15.3 (EN)
unnamed: R74.1, U15.4 (RT/CLK)
unnamed: C21.1, C24.1, C25.1, C27.1, F2.1, R69.1, U15.2 (VIN)
unnamed: C38.2, U17.13 (NR/SS)
PWR_CAN: F5.1, TP30.1 (1_1); also elsewhere on the board
PWR_RS485: F6.1, TP26.1 (1_1); also elsewhere on the board
VBUS: F3.1; also elsewhere on the board
VDBG: F4.1; also elsewhere on the board
V_FIELD: C20.1, C22.1, C26.2, D15.1 (C), D16.1 (C), F2.2, R79.1, R85.1, TP28.1 (1_1), U16.17 (OUT), U16.18 (OUT); also elsewhere on the board

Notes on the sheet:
Step-Down Converter IC
2Amps Fuse
Main 3.3V PSU
Reset for PLC
+5V, 5A
Power Protection IC
5.98A Limit
Auxiliary 3.3V PSU

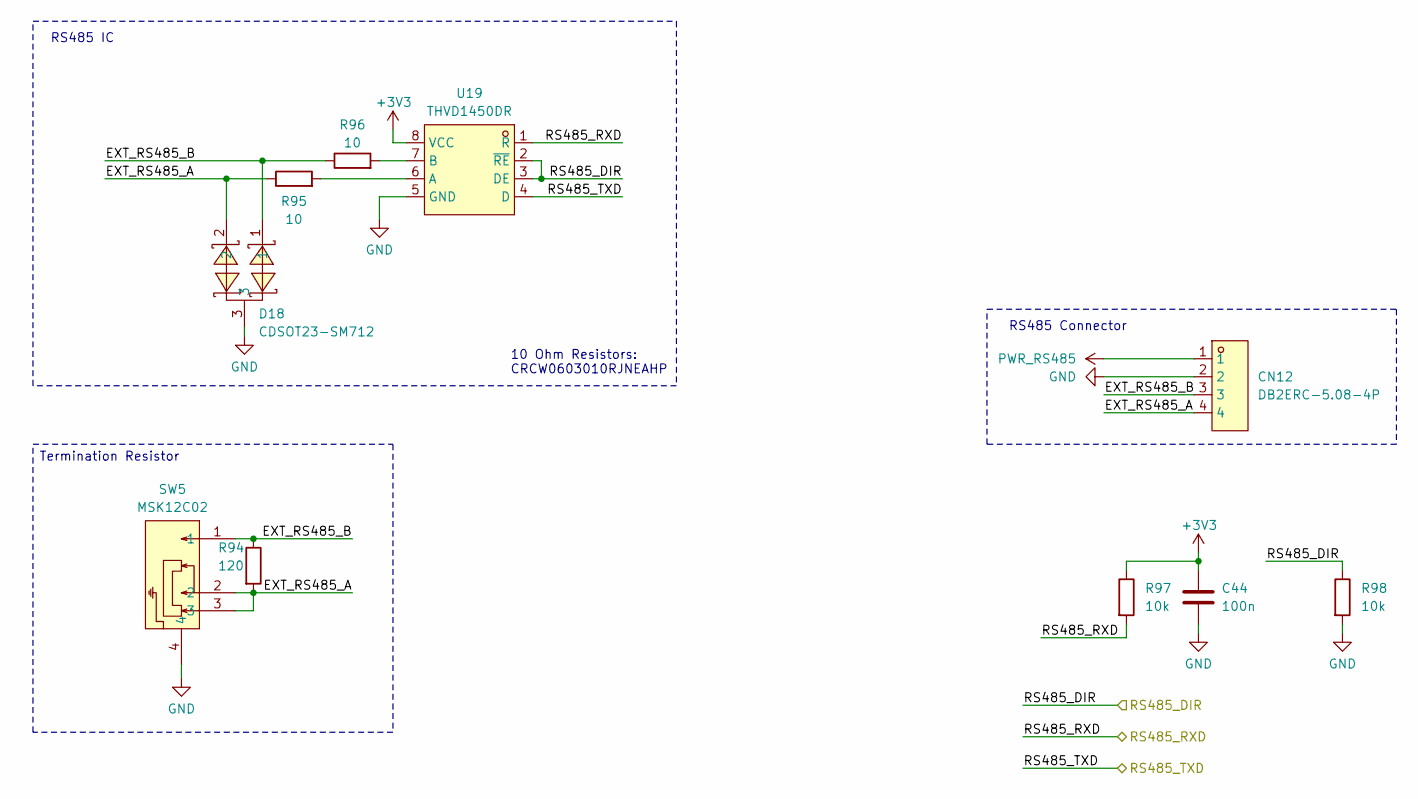
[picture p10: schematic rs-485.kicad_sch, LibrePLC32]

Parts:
C44: 100n; C_0603_1608Metric
CN12: DB2ERC-5.08-4P; CONN-TH_4P-P5.08_DB2ERC-5.08-4P; MPN DB2ERC-5.08-4P-GN; LCSC Part C395753
D18: CDSOT23-SM712; SOT-23_L2.9-W1.3-P1.90-LS2.4-BR; MPN CDSOT23-SM712; LCSC Part C404012
R94: 120; R_0603_1608Metric
R95, R96: 10; R_0603_1608Metric
R97, R98: 10k; R_0603_1608Metric
SW5: MSK12C02; SW-TH_MSK12C02; MPN MSK12C02; LCSC Part C431540
U19: THVD1450DR; SOIC-8_L4.9-W3.9-P1.27-LS6.0-BL; MPN THVD1450DR; LCSC Part C2671361

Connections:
+3V3: C44.1, R97.1, U19.8 (VCC); also elsewhere on the board
/RS-485/EXT_RS485_A: CN12.4, D18.2, R94.2, R95.1, SW5.2, SW5.3
/RS-485/EXT_RS485_B: CN12.3, D18.1, R94.1, R96.1, SW5.1
/RS-485/RS485_DIR: R98.1, U19.2 (~RE), U19.3 (DE); also elsewhere on the board
/RS-485/RS485_RXD: R97.2, U19.1 (R); also elsewhere on the board
/RS-485/RS485_TXD: U19.4 (D); also elsewhere on the board
GND: C44.2, CN12.2, D18.3, R98.2, SW5.4, U19.5 (GND); also elsewhere on the board
unnamed: R95.2, U19.6 (A)
unnamed: R96.2, U19.7 (B)
PWR_RS485: CN12.1; also elsewhere on the board

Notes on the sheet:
RS485 IC
Termination Resistor
10 Ohm Resistors: CRCW0603010RJNEAHP
RS485 Connector

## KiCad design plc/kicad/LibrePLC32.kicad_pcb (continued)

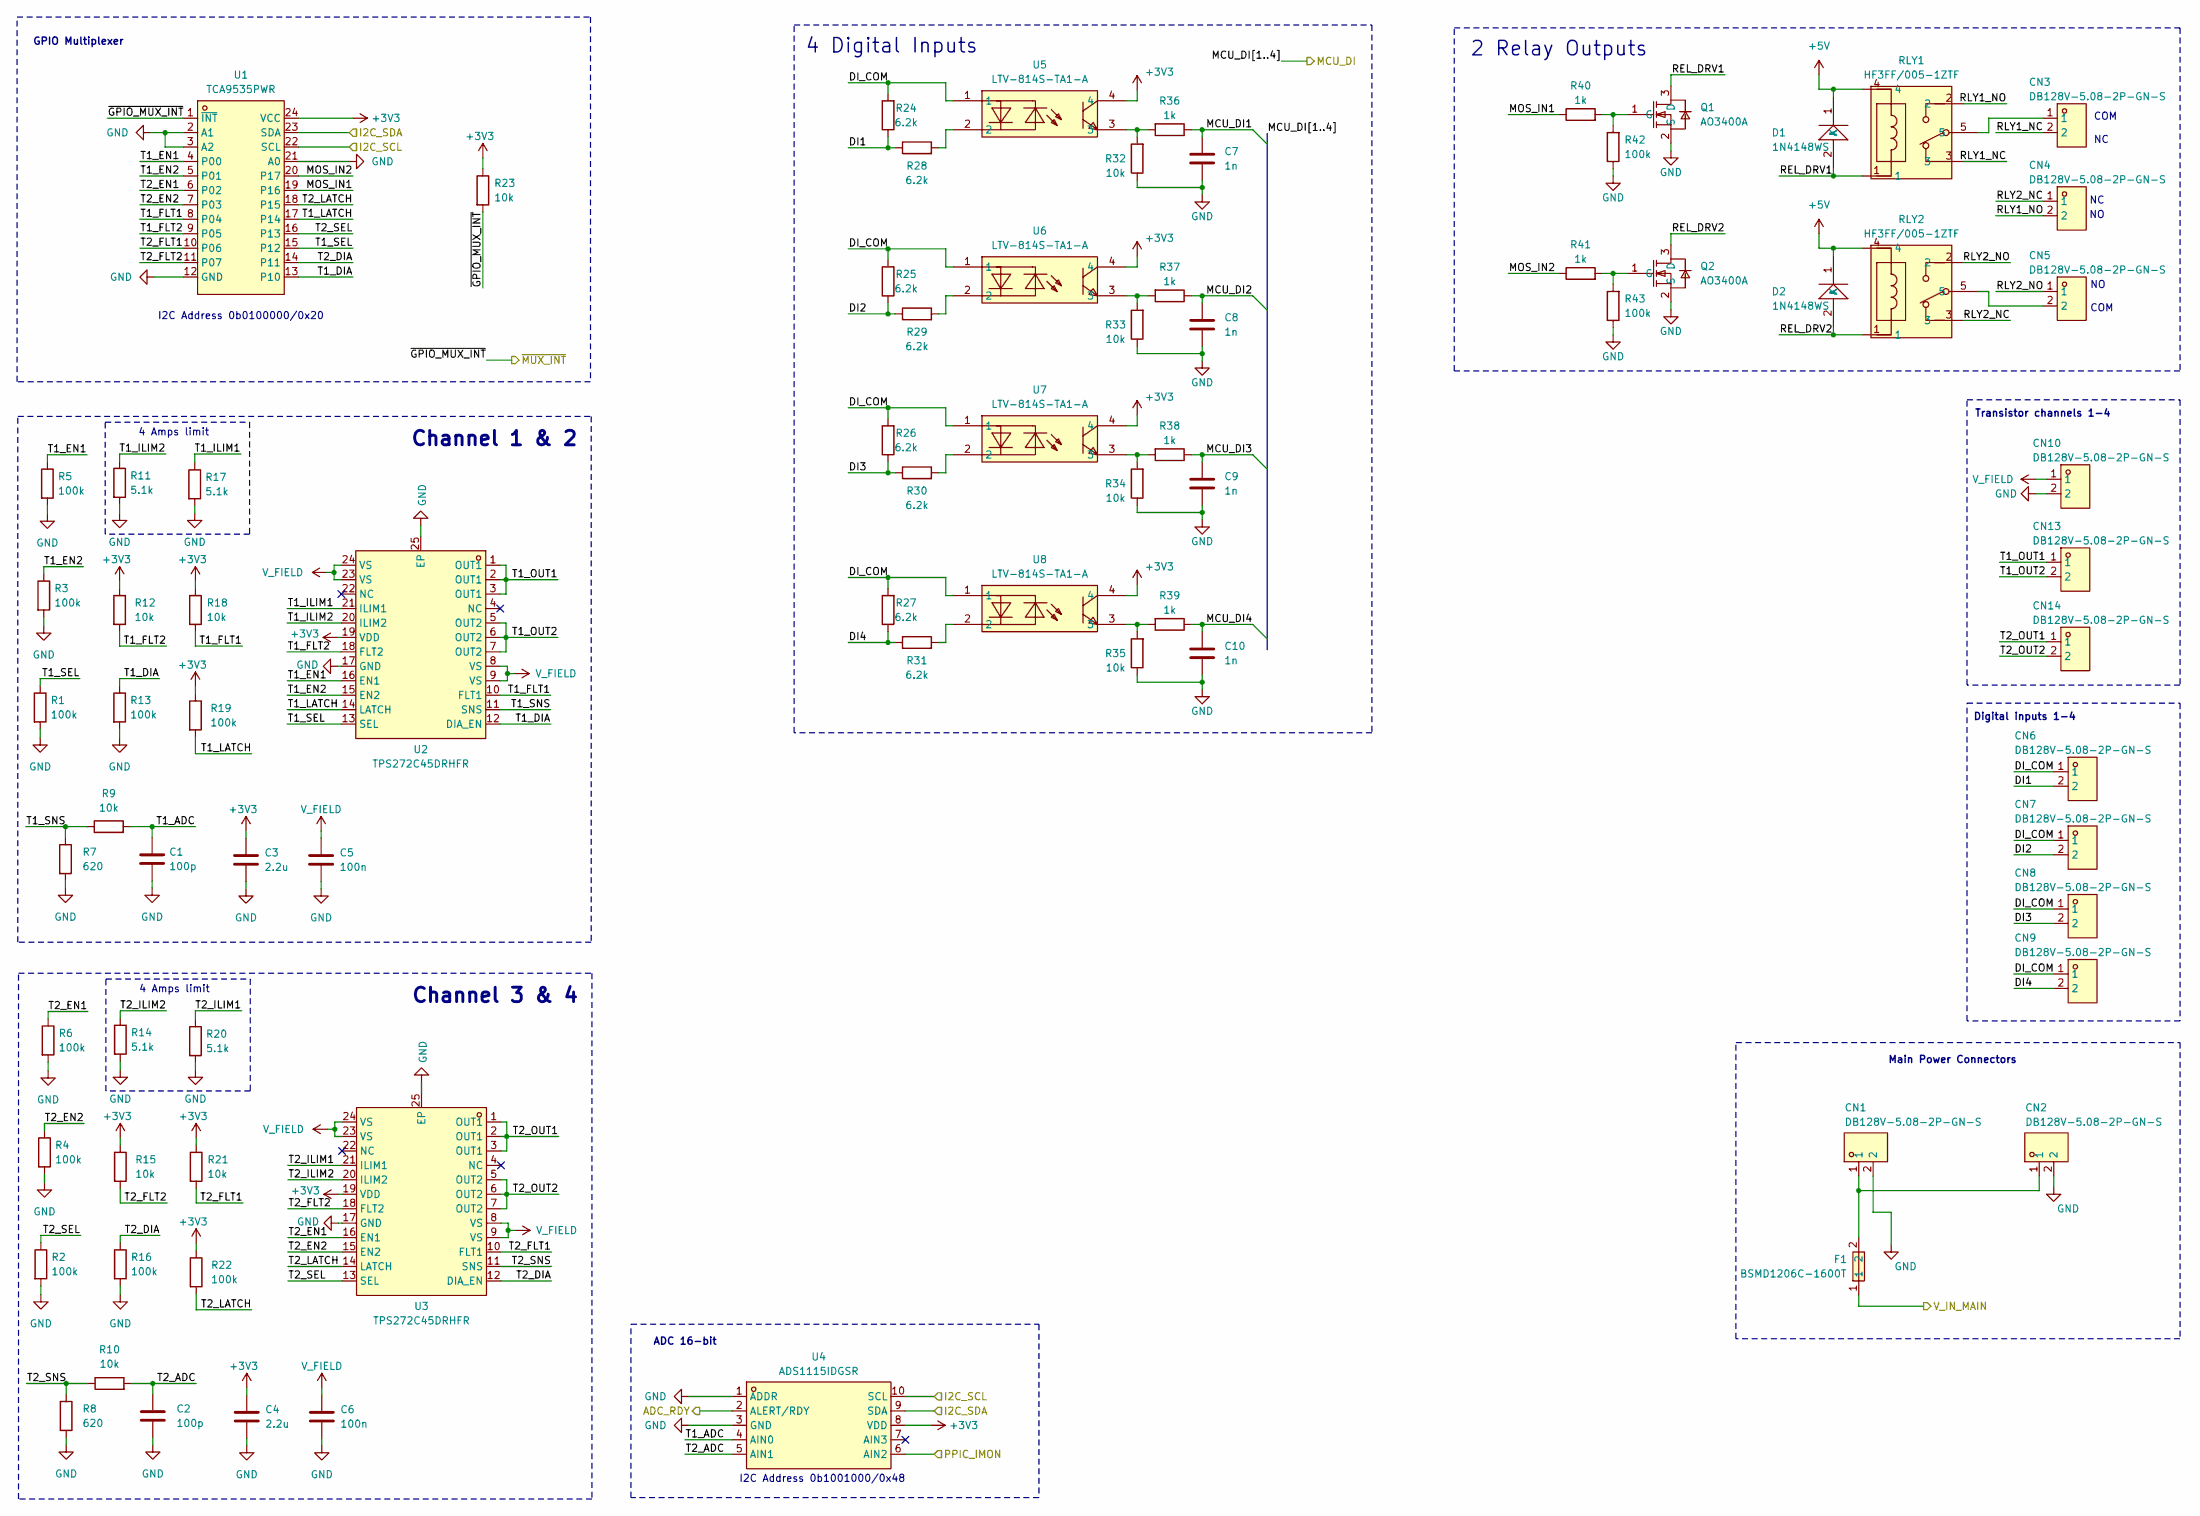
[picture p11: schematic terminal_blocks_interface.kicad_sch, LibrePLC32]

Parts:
C1, C2: 100p; C_0603_1608Metric
C3, C4: 2.2u; C_0603_1608Metric
C5, C6: 100n; C_0603_1608Metric
C7, C8, C9, C10: 1n; C_0603_1608Metric
CN1, CN2, CN3, CN4, CN5, CN6, CN7, CN8, CN9, CN10, CN13, CN14: DB128V-5.08-2P-GN-S; CONN-TH_2P-P5.08_DIBO_DB128V-5.08; MPN DB128V-5.08-2P-GN-S; LCSC Part C2915639
D1, D2: 1N4148WS; SOD-323_L1.8-W1.3-LS2.7-RD; MPN 1N4148WS-E3-08; LCSC Part C129905
F1: BSMD1206C-1600T; F1206; MPN BSMD1206C-1600T; LCSC Part C49328461
Q1, Q2: AO3400A; SOT-23-3_L2.9-W1.3-P1.90-LS2.4-BR; MPN AO3400A; LCSC Part C42419946
R1, R2, R3, R4, R5, R6, R13, R16, R19, R22, R42, R43: 100k; R_0603_1608Metric
R7, R8: 620; R_0603_1608Metric
R9, R10, R12, R15, R18, R21, R23, R32, R33, R34, R35: 10k; R_0603_1608Metric
R11, R14, R17, R20: 5.1k; R_0603_1608Metric
R24, R25, R26, R27, R28, R29, R30, R31: 6.2k; R_0603_1608Metric
R36, R37, R38, R39, R40, R41: 1k; R_0603_1608Metric
RLY1, RLY2: HF3FF/005-1ZTF; RELAY-TH_HF3FF-018-1ZT; MPN HF3FF/005-1ZTF; LCSC Part C2764967
U1: TCA9535PWR; TSSOP-24_L7.8-W4.4-P0.65-LS6.4-BL; MPN TCA9535PWR(UMW); LCSC Part C22396388
U2, U3: TPS272C45DRHFR; VQFN-24_L5.0-W4.0-P0.50-BL-EP-1; MPN TPS272C45DRHFR; LCSC Part C3219943
U4: ADS1115IDGSR; MSOP-10_L3.0-W3.0-P0.50-LS5.0-BL; MPN ADS1115IDGSR; LCSC Part C37593
U5, U6, U7, U8: LTV-814S-TA1-A; OPTO-SMD-4_L4.6-W6.5-P2.54-LS10.3-BL; MPN LTV-814S-TA1-A; LCSC Part C108051

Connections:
+3V3: C3.1, C4.1, R12.1, R15.1, R18.1, R19.1, R21.1, R22.1, R23.1, U1.24 (VCC), U2.19 (VDD), U3.19 (VDD), U4.8 (VDD), U5.4, U6.4, U7.4, U8.4; also elsewhere on the board
+5V: D1.1 (K), D2.1 (K), RLY1.4, RLY2.4; also elsewhere on the board
/MCU/ADC_RDY: U4.2 (ALERT/RDY); also elsewhere on the board
/MCU/I2C_SCL: U1.22 (SCL), U4.10 (SCL); also elsewhere on the board
/MCU/I2C_SDA: U1.23 (SDA), U4.9 (SDA); also elsewhere on the board
/MCU/MCU_DI1: C7.1, R36.1; also elsewhere on the board
/MCU/MCU_DI2: C8.1, R37.1; also elsewhere on the board
/MCU/MCU_DI3: C9.1, R38.1; also elsewhere on the board
/MCU/MCU_DI4: C10.1, R39.1; also elsewhere on the board
/Power/PPIC_IMON: U4.6 (AIN2); also elsewhere on the board
/Power/V_IN_MAIN: F1.1; also elsewhere on the board
/Terminal Blocks Interface/DI1: CN6.2, R24.1, R28.1
/Terminal Blocks Interface/DI2: CN7.2, R25.1, R29.1
/Terminal Blocks Interface/DI3: CN8.2, R26.1, R30.1
/Terminal Blocks Interface/DI4: CN9.2, R27.1, R31.1
/Terminal Blocks Interface/DI_COM: CN6.1, CN7.1, CN8.1, CN9.1, R24.2, R25.2, R26.2, R27.2, U5.1, U6.1, U7.1, U8.1
/Terminal Blocks Interface/MOS_IN1: R40.1, U1.19 (P16)
/Terminal Blocks Interface/MOS_IN2: R41.1, U1.20 (P17)
/Terminal Blocks Interface/REL_DRV1: D1.2 (A), Q1.3 (D), RLY1.1
/Terminal Blocks Interface/REL_DRV2: D2.2 (A), Q2.3 (D), RLY2.1
/Terminal Blocks Interface/RLY1_NC: CN3.2, RLY1.3
/Terminal Blocks Interface/RLY1_NO: CN4.2, RLY1.2
/Terminal Blocks Interface/RLY2_NC: CN4.1, RLY2.3
/Terminal Blocks Interface/RLY2_NO: CN5.1, RLY2.2
/Terminal Blocks Interface/T1_ADC: C1.1, R9.2, U4.4 (AIN0)
/Terminal Blocks Interface/T1_DIA: R13.1, U1.13 (P10), U2.12 (DIA_EN)
/Terminal Blocks Interface/T1_EN1: R5.1, U1.4 (P00), U2.16 (EN1)
/Terminal Blocks Interface/T1_EN2: R3.1, U1.5 (P01), U2.15 (EN2)
/Terminal Blocks Interface/T1_FLT1: R18.2, U1.8 (P04), U2.10 (FLT1)
/Terminal Blocks Interface/T1_FLT2: R12.2, U1.9 (P05), U2.18 (FLT2)
/Terminal Blocks Interface/T1_ILIM1: R17.1, U2.21 (ILIM1)
/Terminal Blocks Interface/T1_ILIM2: R11.1, U2.20 (ILIM2)
/Terminal Blocks Interface/T1_LATCH: R19.2, U1.17 (P14), U2.14 (LATCH)
/Terminal Blocks Interface/T1_OUT1: CN13.1, U2.1 (OUT1), U2.2 (OUT1), U2.3 (OUT1)
/Terminal Blocks Interface/T1_OUT2: CN13.2, U2.5 (OUT2), U2.6 (OUT2), U2.7 (OUT2)
/Terminal Blocks Interface/T1_SEL: R1.1, U1.15 (P12), U2.13 (SEL)
/Terminal Blocks Interface/T1_SNS: R7.1, R9.1, U2.11 (SNS)
/Terminal Blocks Interface/T2_ADC: C2.1, R10.2, U4.5 (AIN1)
/Terminal Blocks Interface/T2_DIA: R16.1, U1.14 (P11), U3.12 (DIA_EN)
/Terminal Blocks Interface/T2_EN1: R6.1, U1.6 (P02), U3.16 (EN1)
/Terminal Blocks Interface/T2_EN2: R4.1, U1.7 (P03), U3.15 (EN2)
/Terminal Blocks Interface/T2_FLT1: R21.2, U1.10 (P06), U3.10 (FLT1)
/Terminal Blocks Interface/T2_FLT2: R15.2, U1.11 (P07), U3.18 (FLT2)
/Terminal Blocks Interface/T2_ILIM1: R20.1, U3.21 (ILIM1)
/Terminal Blocks Interface/T2_ILIM2: R14.1, U3.20 (ILIM2)
/Terminal Blocks Interface/T2_LATCH: R22.2, U1.18 (P15), U3.14 (LATCH)
/Terminal Blocks Interface/T2_OUT1: CN14.1, U3.1 (OUT1), U3.2 (OUT1), U3.3 (OUT1)
/Terminal Blocks Interface/T2_OUT2: CN14.2, U3.5 (OUT2), U3.6 (OUT2), U3.7 (OUT2)
/Terminal Blocks Interface/T2_SEL: R2.1, U1.16 (P13), U3.13 (SEL)
/Terminal Blocks Interface/T2_SNS: R8.1, R10.1, U3.11 (SNS)
/Terminal Blocks Interface/~GPIO_MUX_INT: R23.2, U1.1 (~INT); also elsewhere on the board
GND: C1.2, C2.2, C3.2, C4.2, C5.2, C6.2, C7.2, C8.2, C9.2, C10.2, CN1.2, CN2.2, CN10.2, Q1.2 (S), Q2.2 (S), R1.2, R2.2, R3.2, R4.2, R5.2, R6.2, R7.2, R8.2, R11.2, R13.2, R14.2, R16.2, R17.2, R20.2, R32.1, R33.1, R34.1, R35.1, R42.1, R43.1, U1.2 (A1), U1.3 (A2), U1.12 (GND), U1.21 (A0), U2.17 (GND), U2.25 (EP), U3.17 (GND), U3.25 (EP), U4.1 (ADDR), U4.3 (GND); also elsewhere on the board
unnamed: CN1.1, CN2.1, F1.2
unnamed: CN3.1, RLY1.5
unnamed: CN5.2, RLY2.5
unnamed: Q1.1 (G), R40.2, R42.2
unnamed: Q2.1 (G), R41.2, R43.2
unnamed: R28.2, U5.2
unnamed: R29.2, U6.2
unnamed: R30.2, U7.2
unnamed: R31.2, U8.2
unnamed: R32.2, R36.2, U5.3
unnamed: R33.2, R37.2, U6.3
unnamed: R34.2, R38.2, U7.3
unnamed: R35.2, R39.2, U8.3
V_FIELD: C5.1, C6.1, CN10.1, U2.8 (VS), U2.9 (VS), U2.23 (VS), U2.24 (VS), U3.8 (VS), U3.9 (VS), U3.23 (VS), U3.24 (VS); also elsewhere on the board

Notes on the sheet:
ADC 16-bit
I2C Address 0b0100000/0x20
2 Relay Outputs
I2C Address 0b1001000/0x48
4 Amps limit
4 Digital Inputs
Transistor channels 1-4
GPIO Multiplexer
Channel 1 & 2
COM NC
Digital inputs 1-4
Main Power Connectors
NO COM
Channel 3 & 4

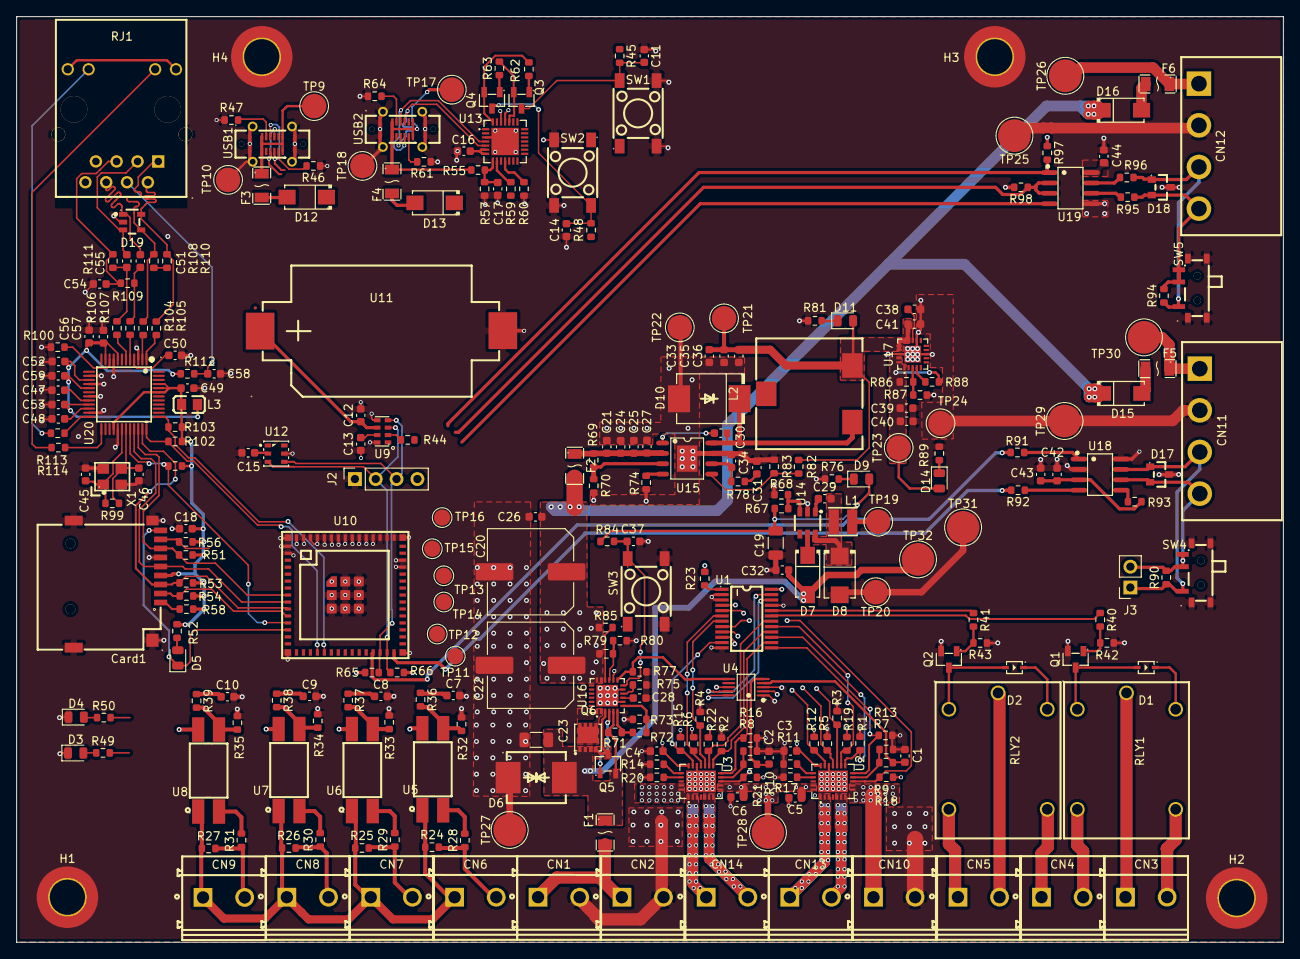
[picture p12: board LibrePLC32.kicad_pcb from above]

Board: 4 copper layers, 154.5 x 112.9 mm, 283 parts (0 on the bottom side), 181 nets.

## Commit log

2026-04-27 Added microSD card
    [ext_interface.kicad_sch, mcu.kicad_sch]
2026-04-27 Corrected TVS duplicated
    [ethernet.kicad_sch]
2026-04-28 Added setup leds & shared SPI bus
    [LibrePLC32.kicad_sch, ethernet.kicad_sch, mcu.kicad_sch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]
2026-04-28 Fixed ADC pins & rc filter
    [mcu.kicad_sch, terminal_blocks_interface.kicad_sch]
2026-04-29 TPS54560 changed to TPS54560B
    [power.kicad_sch]
2026-04-29 Create TPS2663x _TPS1663x_Design_Calculator_revB.xlsx
    [TPS2663x _TPS1663x_Design_Calculator_revB.xlsx]
2026-04-29 Modified TPS26630 resistor values
    [TPS2663x _TPS1663x_Design_Calculator_revB.xlsx, power.kicad_sch]
2026-04-29 Changed TLV76733 to TPS7A52-Q1
    [power.kicad_sch]
2026-04-29 Updated LMR16006X circuit
    [power.kicad_sch]
2026-04-29 Removed CAN FLT resistor
    [LibrePLC32.kicad_pcb, can.kicad_sch]
2026-04-29 Added more wiring
    [LibrePLC32.kicad_pcb, rs-485.kicad_sch]
2026-04-30 Eliminated series diode to output transistors
    [terminal_blocks_interface.kicad_sch]
2026-04-30 Added TPS54560 PCB placement
    [LibrePLC32.kicad_pcb, power.kicad_sch]
2026-04-30 LMR16006X PCB placement
    [LibrePLC32.kicad_pcb, power.kicad_sch]
2026-04-30 TPS26630 PCB placement
    [LibrePLC32.kicad_pcb, power.kicad_sch]
2026-04-30 TPS7A52-Q1 PCB placement
    [LibrePLC32.kicad_pcb, power.kicad_sch, terminal_blocks_interface.kicad_sch]
2026-05-03 Updated W5500 to reference schematic
    [LibrePLC32.kicad_pcb, ethernet.kicad_sch]
2026-05-03 Updated W5500 PCB Placement
    [LibrePLC32.kicad_pcb]
2026-05-03 SD Card PCB Placement
    [LibrePLC32.kicad_pcb, ethernet.kicad_sch, mcu.kicad_sch]
2026-05-03 PCB placement of USB circuits
    [LibrePLC32.kicad_pcb, mcu.kicad_sch]
2026-05-03 Rearranged small PCB placements
    [LibrePLC32.kicad_pcb, can.kicad_sch, ethernet.kicad_sch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]
2026-05-03 TPS272C45 PCB placement
    [LibrePLC32.kicad_pcb, terminal_blocks_interface.kicad_sch]
2026-05-04 PCB placement updates
    [LibrePLC32.kicad_pcb, mcu.kicad_sch, terminal_blocks_interface.kicad_sch]
2026-05-05 Updated PCB placement
    [LibrePLC32.kicad_pcb, mcu.kicad_sch, power.kicad_sch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]
2026-05-06 Added mounting holes & PCB outline
    [LibrePLC32.kicad_pcb, mcu.kicad_sch, power.kicad_sch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]
2026-05-06 Updated switch placement for can & rs485
    [mcu.kicad_sch]
2026-05-07 Updated PCB placement & graphics
    [mcu.kicad_sch]
2026-05-07 Added logo on PCB
2026-05-08 Added KiCAD logo on PCB
2026-05-08 Added 3D model of the board
2026-05-12 Added exclusion zone under relays
2026-05-17 Fixed shorting resistors for CAN & RS485
    [can.kicad_sch, rs-485.kicad_sch]
2026-06-05 Changed CAN & RS485 to input voltage unprotected
    [LibrePLC32.kicad_sch, power.kicad_sch, terminal_blocks_interface.kicad_sch]
2026-06-10 Tuned USB to 90ohms
    [mcu.kicad_sch]
2026-06-10 Updated SMD fuses to fuse holders
    [power.kicad_sch, terminal_blocks_interface.kicad_sch]
2026-06-11 Modified 3V3 aux to zener
    [power.kicad_sch]
2026-06-11 Reannotated schematic
2026-06-11 Silkscreen fixes
2026-06-11 Added isolated CAN bus
    [LibrePLC32.kicad_sch, can.kicad_sch, mcu.kicad_sch]
2026-06-11 Added isolated RS-485
    [can.kicad_sch, rs-485.kicad_sch]
2026-06-12 Routed Ethernet at 100 ohms
    [ethernet.kicad_sch]
2026-06-12 Slight silkscreen & component adjustment
    [power.kicad_sch]
2026-06-15 Added more mounting holes
    [LibrePLC32.kicad_sch, mcu.kicad_sch]
2026-06-15 Added amperage to silkscreen of fuse holders
2026-06-15 BOM Consolidation
    - CP2102N Vdbg divider: 22.1k→5.1k, 47.5k→10k (gives 3.29V)
    - I²C pull-ups (R65,R66): 4.7k→5.1k (verified ok)
    - Buck UVLO (R69,R70): 442k→100k, 90.9k→2×10k (UVLO = 7V)
    - TPS272C45D ILIM (R75): 3k→3×10k (~6A limit)
    - PPIC IMON + ETH_EXPRESS (R77,R100): 12.4k→2×6.2k
    - Buck compensation (R78): 16.9k→10k+6.2k+620 series
    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
    [TPS2663x _TPS1663x_Design_Calculator_revB.xlsx, ethernet.kicad_sch, mcu.kicad_sch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]
2026-06-15 BOM consolidation
    Consolidated two more resistor values
    [power.kicad_sch]
2026-06-15 Hidden mounting hole IDs
2026-06-15 Modified PPIC_PGOOD to 100k
    [power.kicad_sch]
2026-06-16 Added fuse info
    [terminal_blocks_interface.kicad_sch]
2026-07-07 Fixed silkscreen of ethernet
    [can.kicad_sch, ethernet.kicad_sch, mcu.kicad_sch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]
